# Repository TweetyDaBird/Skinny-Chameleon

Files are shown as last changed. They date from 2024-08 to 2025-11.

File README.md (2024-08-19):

# The Skinny Chameleon 

Chameleon

## Features
**The Skinny Chameleon is a grid type orthogonal keyboard with two optional layouts in one single PCB. It's a direct offshoot of the original Chameleon, only made to fit the Preonic's and Planck's non-standard key spacing.** Being able to break off the bottom row allows both a 5x12 layout acting as a replacement PCB for OLKB's Preonic and a 4x12 layout for the equally popular little brother Planck on the same PCB. 

Using the non-standard 19.00 mm grid spacing this PCB fit's all original cases for Preonic & Planck, and should fit all the various 'aftermarket' keyboard cases intended for these PCB's as well.

Being fully hot-swap and with PCB mounted stabilizers, Chameleon adds support for up to four encoders and a bottom row allowing either a single stabilized 2u key or two 2u keys in the middle, allowing for a layout that suits most users. If used as a 5 row keyboard, the bottom encoders can alternatively be placed at the edges on the second row, but **not more than one per corner.** 

The Chameleon features 8 bottomfacing RGB LEDs for underglow effects or to be used for layer indication or similar. 

**Please Note! This PCB fits original Planck/Preonic cases! NOT BM40/JJ40/JJ50!**

### Main Features:
* QMK and VIAL compatible, fully programmable keyboard**
* RP2040 MCU, Dual-core Arm Cortex M0+ processor, flexible clock running up to 133 MHz
* 264KB of SRAM, and 4MB of on-board Flash memory
* USB-C connector, (USB 1.1 device and host support)
* Low-power sleep and dormant modes
* Drag-and-drop programming using mass storage over USB
* Kaihl hot-swap sockets for Cherry MX compatible switches (3 & 5-pin)
* Cherry Style PCB mounted stabilizers
* Two main layouts:
	* 5x12 with 58 to 60 keys
	* 4x12 with 46 to 48 keys (Break off bottom row) 
* Configurable bottom row:
	* Full 1u grid
	* 1x centered, stabilized 2u key
	* 2x centered,  stabilized 2u keys

### Optional add-ons:
* Support for up to 4 rotary encoders **(one encoder per corner)**
* Optional RGB underglow (8x SK6812 mini-e)

**These options requires additional components not included in this listing and sold separately.**

## Assembly
**Little or no tools at all needed!** The PCB can be delivered fully soldered and ready to use, either as a full matrix, or with your selection of rotary encoders. If ordered fully soldered, the bottom row for the size specified (4x12/5x12) is soldered, and accepts both a full 1u grid and 2u keys without any changes.

**Or as a "DIY Kit" with some soldering needed**. As a DIY kit the hotswap sockets for the 6 encoder positions (corners) and the 2u keys are left unsoldered, and you can add them as your layout requires to corners not using an encoder, and to the bottom row you choose to use. (A total if 9 sockets included for soldering).

The optional RGB LED's needs to be soldered in place if used. (8 pcs, SK681x mini-E)

_The RGB LED's and encoders are all pre-soldered together with the required hotswap sockets at no extra cost, if the soldering option is selected and all parts needed are purchased in the same order._

# Case & Plate
**The design is made to fit any Planck or Preonic case and plate, and act as a drop-in replacement PCB.** It does *not* fit any case not advertised as specific fitment for these. 

**Any mounting hardware should accompany the case, and is not supplied with the PCB.** This means you will have to save and reuse the hardware with your originial case. 

**The solder on studs can be removed from your original PCB and re-used.**  Or, you can choose to buy replacement studs as an add-on, and not have to bother with the removal. Please note that the replacement studs are slightly loose in the holes to allow the use of both types (the original ones are a speciality item made for OLKB, I'm using the nearest off the shelf replacement), and they _absolutely need_ to be soldered on to the PCB to be useful. I highly suggest attaching them to the case, placing the PCB and solder as they are aligned.

***Change for version 1.10*** New PCB's will _NOT_ be able to fit the unusually sized original OLKB studs. Having to make a choice between the weird size making off the shelf studs be hard to center and re-using the original studs (which takes some skill), I'm choosing the off the shelf ones I can supply at a decent price. 
# Making Chameleon yourself
**Chameleon is open source / open hardware, and can be manufactured by anyone. The release contains all the neccesary files like parts lists, positions files etc for a full PCB/SMT production.** 

The formatting and files are geared towards [JLCPCB](http://jlcpcb.com), but never tested as such, as I only manufacture the PCB then do the assembly myself (at least until this reaches a volume justifying full SMT production).

The components are small enough that you would have to be highly skilled to attempt to assemble this either as hand soldered, or small scale/DIY SMT. I would highly recommend ordering the PCB as fully assembled unless you know you have the neccesary skill-set.

## Buy a kit!
I sell complete kits, making it easy to build your keyboard, and it also supports prototypes for new wacky ones. 



## Discord for build help and discussions!

<a href="https://discord.gg/G6QzcJQUnm">Discuss on Discord</a>

# License

[][cc-by-sa] - This work is licensed under a
[Creative Commons Attribution-ShareAlike 4.0 International License][cc-by-sa].

[cc-by-sa]: http://creativecommons.org/licenses/by-sa/4.0/
[cc-by-sa-shield]: https://img.shields.io/badge/License-CC%20BY--SA%204.0-lightgrey.svg

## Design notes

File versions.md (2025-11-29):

v1.20 - pushed out usb connector, refactored encoder footprints, refactored switch footprints with reinforced pads(larger via).

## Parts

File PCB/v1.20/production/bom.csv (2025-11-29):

Designator | Footprint | Quantity | Value | LCSC Part #
C1, C11, C12, C8 | 0402 | 4 | 1uF | C52923
C10, C13, C16, C17, C18, C19, C2, C20, C21, C22, C23, C3, C4, C5, C6, C7, C9 | 0402 | 17 | 100nF | C1525
C14, C15 | 0402 | 2 | 30pF | C1570
D1, D10, D11, D12, D13, D14, D15, D16, D17, D18, D19, D2, D20, D21, D22, D23, D24, D25, D26, D27, D28, D29, D3, D30, D31, D32, D33, D34, D35, D36, D37, D38, D39, D4, D40, D41, D42, D43, D44, D45, D46, D47, D48, D49, D5, D50, D51, D52, D53, D54, D55, D56, D57, D58, D59, D6, D60, D7, D8, D9 | D_SOD-323 | 60 | 1N4148W | C2128
F1 | 0603 | 1 | 0603L050/6AR | C163116
FB1, FB2 | 0603 | 2 | BLM18SG700TZ1D | C1002
R1, R2 | 0402 | 2 | 5.1K | C25905
R10, R4 | 0402 | 2 | 1K | C11702
R3, R7 | 0402 | 2 | 10K | C25744
R5, R6 | 0402 | 2 | 27R | C321419
SW10, SW11, SW13, SW14, SW15, SW16, SW17, SW18, SW19, SW2, SW20, SW21, SW22, SW23, SW24, SW25, SW26, SW27, SW28, SW29, SW3, SW30, SW31, SW32, SW33, SW34, SW35, SW36, SW38, SW39, SW4, SW40, SW41, SW42, SW43, SW44, SW45, SW46, SW47, SW5, SW50, SW51, SW52, SW53, SW54, SW55, SW56, SW57, SW58, SW59, SW6, SW61, SW62, SW63, SW64, SW65, SW66, SW7, SW8, SW9 | SW_MX_HotSwap_reinforced | 60 | PG151101S11 | C2803348
SW67, SW68 | YTSA010 | 2 | YTSA010 | C967783
U1 | SOT-23-5 | 1 | SPX3819M5-L-3-3/TR | C9055
U2 | USON-8_4x3mm_P0.8mm | 1 | W25Q32JVUUIQ | C2999380
U3 | QFN-56-1EP_7x7mm_P0.4mm_EP3.2x3.2mm | 1 | RP2040 | C2040
U4 | SOT-23-5 | 1 | SN74LV1T34DBV | C100024
U5 | SOT-23-6 | 1 | SRV05-4 | C20615829
USB1 | HRO_TYPE-C-31-M-12 | 1 | USB_C_Receptacle_USB2.0 | C165948
Y1 | Crystal_SMD_2520-4Pin_2.5x2.0mm | 1 | TXM12M0004252LBCEO00T | C284156

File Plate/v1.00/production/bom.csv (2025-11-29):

Designator | Footprint | Quantity | Value | LCSC Part #
SW1, SW10, SW11, SW12, SW13, SW14, SW15, SW16, SW17, SW18, SW19, SW2, SW20, SW21, SW22, SW23, SW24, SW25, SW26, SW27, SW28, SW29, SW3, SW30, SW31, SW32, SW33, SW34, SW35, SW36, SW37, SW38, SW39, SW4, SW40, SW41, SW42, SW44, SW45, SW46, SW47, SW48, SW5, SW50, SW51, SW52, SW53, SW54, SW57, SW58, SW59, SW6, SW63, SW7, SW8, SW9 | SW_MX_Plate_Placeholder_nodrill_NOBORDER_13,9 | 56 | PG151101S11 | C2803348

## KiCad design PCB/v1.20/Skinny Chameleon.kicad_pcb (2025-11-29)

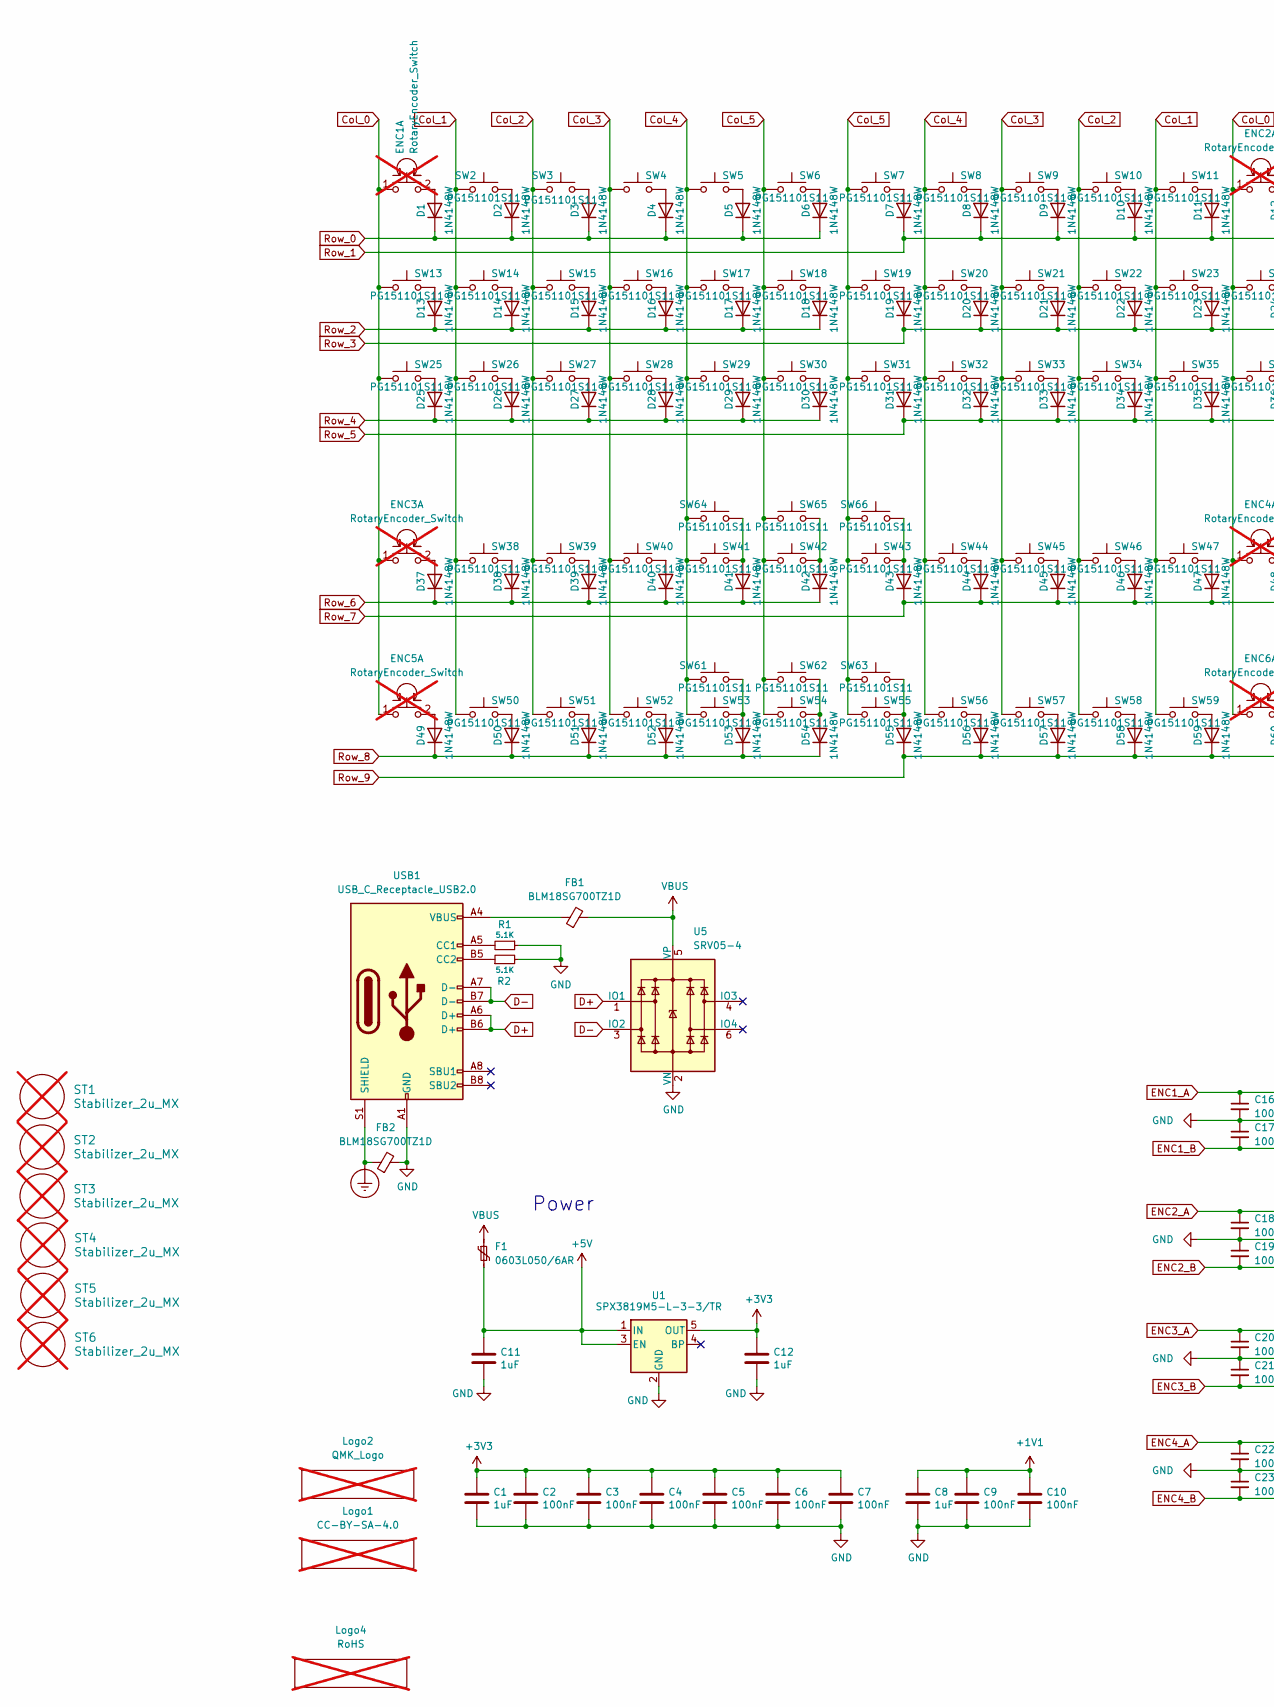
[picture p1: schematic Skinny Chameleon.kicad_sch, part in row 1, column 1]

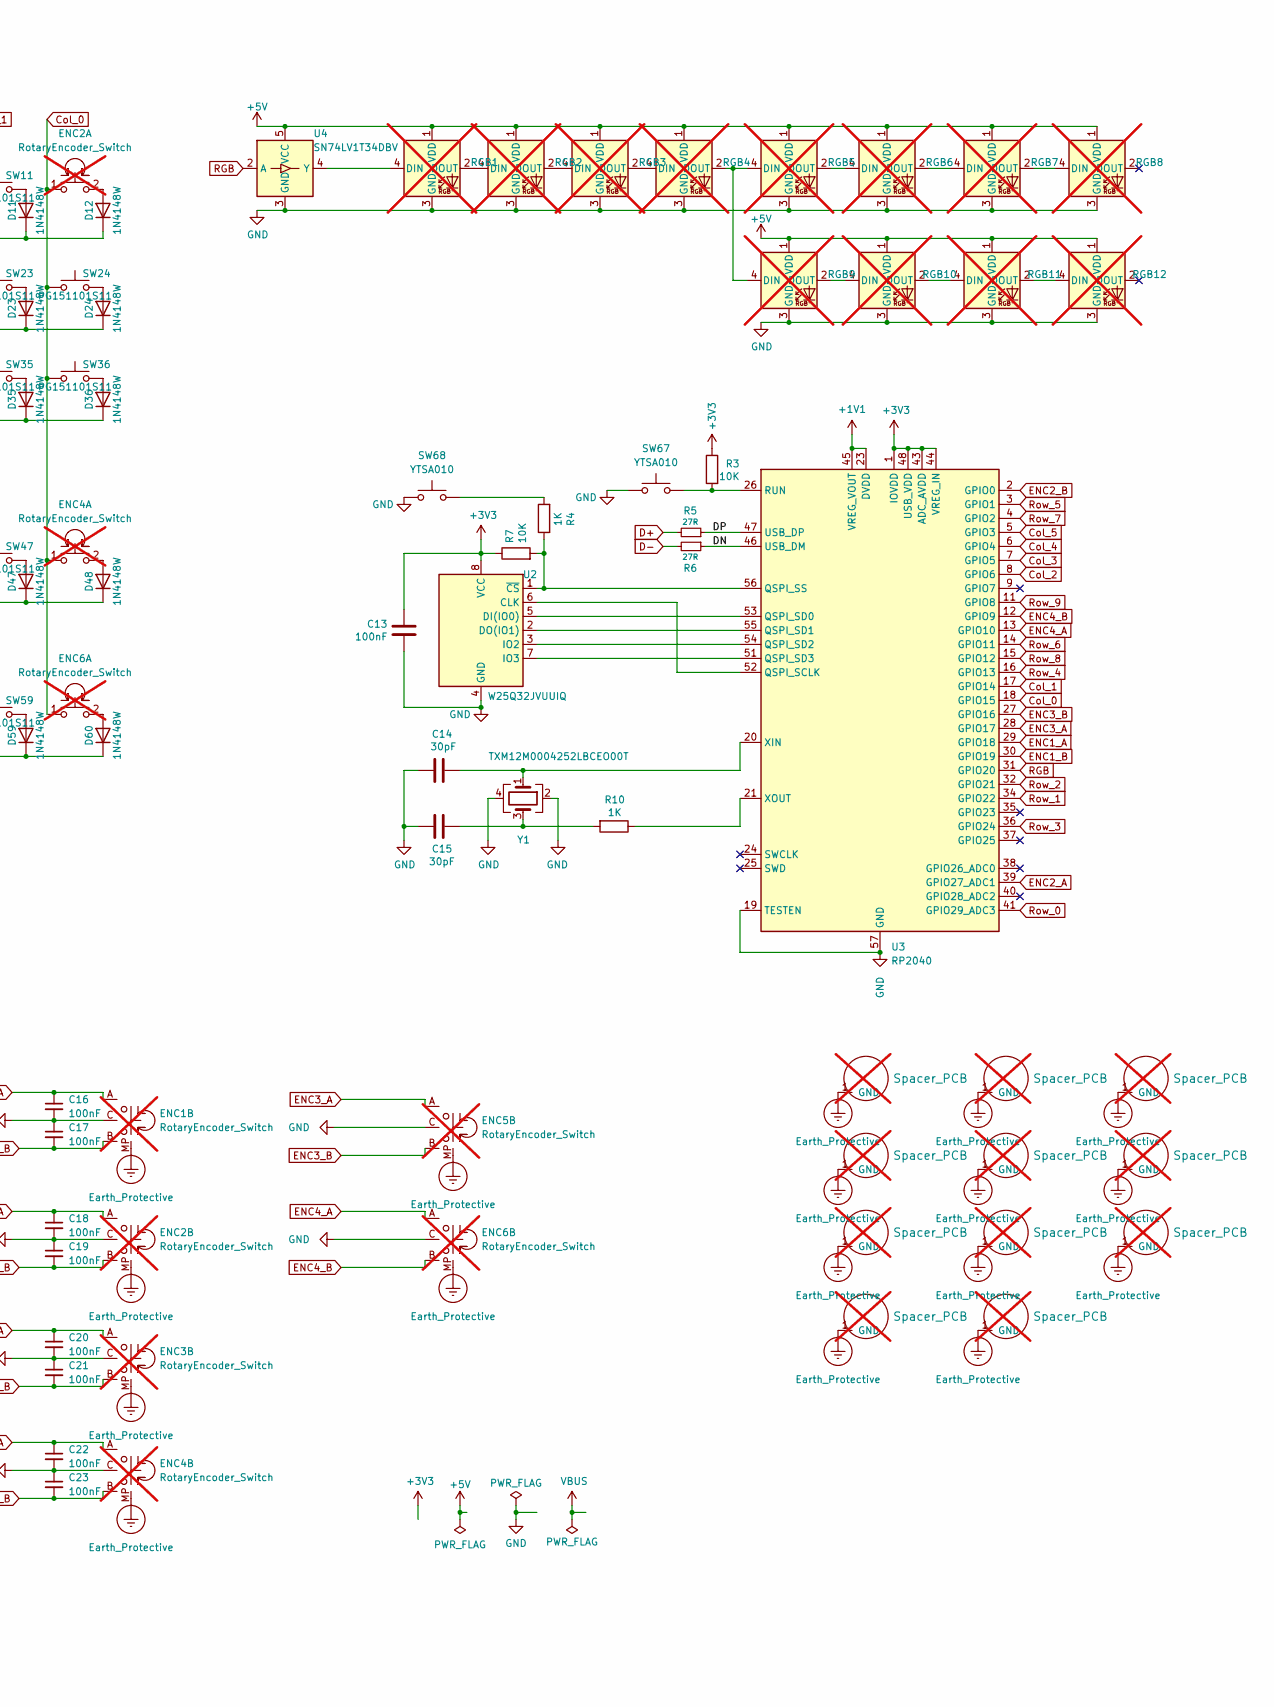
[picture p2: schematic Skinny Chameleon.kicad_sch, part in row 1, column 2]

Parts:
C1, C8, C11, C12: 1uF; C_0402_1005Metric; LCSC Part # C52923
C2, C3, C4, C5, C6, C7, C9, C10, C13, C16, C17, C18, C19, C20, C21, C22, C23: 100nF; C_0402_1005Metric; LCSC Part # C1525
C14, C15: 30pF; C_0402_1005Metric; LCSC Part # C1570
D1, D2, D3, D4, D5, D6, D7, D8, D9, D10, D11, D12, D13, D14, D15, D16, D17, D18, D19, D20, D21, D22, D23, D24, D25, D26, D27, D28, D29, D30, D31, D32, D33, D34, D35, D36, D37, D38, D39, D40, D41, D42, D43, D44, D45, D46, D47, D48, D49, D50, D51, D52, D53, D54, D55, D56, D57, D58, D59, D60: 1N4148W; D_SOD-323; LCSC Part # C2128
ENC1, ENC2: RotaryEncoder_Switch; SW_MX_HotSwap_Encoder_reinforced; not fitted
ENC3, ENC4, ENC5, ENC6: RotaryEncoder_Switch; SW_MX_HotSwap_Encoder_inverted_reinforced; not fitted
F1: 0603L050/6AR; R_0603_1608Metric; LCSC Part # C163116
FB1, FB2: BLM18SG700TZ1D; C_0603_1608Metric_Pad1.08x0.95mm_HandSolder; LCSC Part # C1002
H1, H2, H4, H5, H6, H7, H9, H11, H12, H13, H14: Spacer_PCB; Planck Spacer; not fitted
Logo1: CC-BY-SA-4.0; CC_BY_SA_40_line; not fitted
Logo2: QMK_Logo; qmk logo; not fitted
Logo4: RoHS; RoHs; not fitted
R1, R2: 5.1K; R_0402_1005Metric; LCSC Part # C25905
R3, R7: 10K; R_0402_1005Metric; LCSC Part # C25744
R4, R10: 1K; R_0402_1005Metric; LCSC Part # C11702
R5, R6: 27R; R_0402_1005Metric; LCSC Part # C321419
RGB1, RGB2, RGB3, RGB4, RGB5, RGB6, RGB7, RGB8, RGB9, RGB10, RGB11, RGB12: SK6812MINI-E; RGB_SK6812MINI-E; not fitted
ST1, ST2, ST3, ST4, ST5, ST6: Stabilizer_2u_MX; Stabilizer_Cherry_MX_2.00u; not fitted
SW2, SW3, SW4, SW5, SW6, SW7, SW8, SW9, SW10, SW11, SW13, SW14, SW15, SW16, SW17, SW18, SW19, SW20, SW21, SW22, SW23, SW24, SW25, SW26, SW27, SW28, SW29, SW30, SW31, SW32, SW33, SW34, SW35, SW36, SW38, SW39, SW40, SW41, SW42, SW43, SW44, SW45, SW46, SW47, SW50, SW51, SW52, SW53, SW54, SW55, SW56, SW57, SW58, SW59, SW61, SW62, SW63, SW64, SW65, SW66: PG151101S11; SW_MX_HotSwap_reinforced; LCSC Part # C2803348
SW67, SW68: YTSA010; LCSC Part # C967783
U1: SPX3819M5-L-3-3/TR; SOT-23-5; LCSC Part # C9055
U2: W25Q32JVUUIQ; USON-8_4x3mm_P0.8mm; LCSC Part # C2999380
U3: RP2040; QFN-56-1EP_7x7mm_P0.4mm_EP3.2x3.2mm; LCSC Part # C2040
U4: SN74LV1T34DBV; SOT-23-5; LCSC Part # C100024
U5: SRV05-4; SOT-23-6; LCSC Part # C20615829
USB1: USB_C_Receptacle_USB2.0; HRO_TYPE-C-31-M-12; LCSC Part # C165948
Y1: TXM12M0004252LBCEO00T; Crystal_SMD_2520-4Pin_2.5x2.0mm; LCSC Part # C284156

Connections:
+1V1: C8.1, C9.1, C10.1, U3.23 (DVDD), U3.45 (VREG_VOUT), U3.50 (DVDD)
+3V3: C1.1, C2.1, C3.1, C4.1, C5.1, C6.1, C7.1, C12.1, C13.1, R3.1, R7.1, U1.5 (OUT), U2.8 (VCC), U3.1 (IOVDD), U3.10 (IOVDD), U3.22 (IOVDD), U3.33 (IOVDD), U3.42 (IOVDD), U3.43 (ADC_AVDD), U3.44 (VREG_IN), U3.48 (USB_VDD), U3.49 (IOVDD)
+5V: C11.1, F1.2, RGB1.1 (VDD), RGB2.1 (VDD), RGB3.1 (VDD), RGB4.1 (VDD), RGB5.1 (VDD), RGB6.1 (VDD), RGB7.1 (VDD), RGB8.1 (VDD), RGB9.1 (VDD), RGB10.1 (VDD), RGB11.1 (VDD), RGB12.1 (VDD), U1.1 (IN), U1.3 (EN), U4.5 (VCC)
/DN: R6.1, U3.46 (USB_DM)
/DP: R5.1, U3.47 (USB_DP)
Col_0: ENC1.1, ENC1.S1, ENC2.1, ENC2.S1, ENC3.1, ENC3.S1, ENC4.1, ENC4.S1, ENC5.1, ENC5.S1, ENC6.1, ENC6.S1, SW13.1, SW24.1, SW25.1, SW36.1, U3.18 (GPIO15)
Col_1: SW2.2, SW11.1, SW14.1, SW23.1, SW26.1, SW35.1, SW38.1, SW47.1, SW50.1, SW59.1, U3.17 (GPIO14)
Col_2: SW3.2, SW10.1, SW15.1, SW22.1, SW27.1, SW34.1, SW39.1, SW46.1, SW51.1, SW58.1, U3.8 (GPIO6)
Col_3: SW4.1, SW9.1, SW16.1, SW21.1, SW28.1, SW33.1, SW40.1, SW45.1, SW52.1, SW57.1, U3.7 (GPIO5)
Col_4: SW5.1, SW8.1, SW17.1, SW20.1, SW29.1, SW32.1, SW41.1, SW44.1, SW53.1, SW56.1, SW61.2, SW64.2, U3.6 (GPIO4)
Col_5: SW6.1, SW7.1, SW18.1, SW19.1, SW30.1, SW31.1, SW42.1, SW43.1, SW54.1, SW55.1, SW62.1, SW63.2, SW65.1, SW66.2, U3.5 (GPIO3)
D+: R5.2, U5.1 (IO1), USB1.A6 (D+), USB1.B6 (D+)
D-: R6.2, U5.3 (IO2), USB1.A7 (D-), USB1.B7 (D-)
ENC1_A: C16.1, ENC1.A, U3.29 (GPIO18)
ENC1_B: C17.2, ENC1.B, U3.30 (GPIO19)
ENC2_A: C18.1, ENC2.A, U3.39 (GPIO27_ADC1)
ENC2_B: C19.2, ENC2.B, U3.2 (GPIO0)
ENC3_A: C20.1, ENC3.A, ENC5.A, U3.28 (GPIO17)
ENC3_B: C21.2, ENC3.B, ENC5.B, U3.27 (GPIO16)
ENC4_A: C22.1, ENC4.A, ENC6.A, U3.13 (GPIO10)
ENC4_B: C23.2, ENC4.B, ENC6.B, U3.12 (GPIO9)
unnamed: C15.1, R10.2, Y1.3
unnamed: D1.2 (A), ENC1.2, ENC1.S2
unnamed: D2.2 (A), SW2.1
unnamed: D3.2 (A), SW3.1
unnamed: D4.2 (A), SW4.2
unnamed: D5.2 (A), SW5.2
unnamed: D6.2 (A), SW6.2
unnamed: D7.2 (A), SW7.2
unnamed: D8.2 (A), SW8.2
unnamed: D9.2 (A), SW9.2
unnamed: D10.2 (A), SW10.2
unnamed: D11.2 (A), SW11.2
unnamed: D12.2 (A), ENC2.2, ENC2.S2
unnamed: D13.2 (A), SW13.2
unnamed: D14.2 (A), SW14.2
unnamed: D15.2 (A), SW15.2
unnamed: D16.2 (A), SW16.2
unnamed: D17.2 (A), SW17.2
unnamed: D18.2 (A), SW18.2
unnamed: D19.2 (A), SW19.2
unnamed: D20.2 (A), SW20.2
unnamed: D21.2 (A), SW21.2
unnamed: D22.2 (A), SW22.2
unnamed: D23.2 (A), SW23.2
unnamed: D24.2 (A), SW24.2
unnamed: D25.2 (A), SW25.2
unnamed: D26.2 (A), SW26.2
unnamed: D27.2 (A), SW27.2
unnamed: D28.2 (A), SW28.2
unnamed: D29.2 (A), SW29.2
unnamed: D30.2 (A), SW30.2
unnamed: D31.2 (A), SW31.2
unnamed: D32.2 (A), SW32.2
unnamed: D33.2 (A), SW33.2
unnamed: D34.2 (A), SW34.2
unnamed: D35.2 (A), SW35.2
unnamed: D36.2 (A), SW36.2
unnamed: D37.2 (A), ENC3.2, ENC3.S2
unnamed: D38.2 (A), SW38.2
unnamed: D39.2 (A), SW39.2
unnamed: D40.2 (A), SW40.2
unnamed: D41.2 (A), SW41.2, SW64.1
unnamed: D42.2 (A), SW42.2, SW65.2
unnamed: D43.2 (A), SW43.2, SW66.1
unnamed: D44.2 (A), SW44.2
unnamed: D45.2 (A), SW45.2
unnamed: D46.2 (A), SW46.2
unnamed: D47.2 (A), SW47.2
unnamed: D48.2 (A), ENC4.2, ENC4.S2
unnamed: D49.2 (A), ENC5.2, ENC5.S2
unnamed: D50.2 (A), SW50.2
unnamed: D51.2 (A), SW51.2
unnamed: D52.2 (A), SW52.2
unnamed: D53.2 (A), SW53.2, SW61.1
unnamed: D54.2 (A), SW54.2, SW62.2
unnamed: D55.2 (A), SW55.2, SW63.1
unnamed: D56.2 (A), SW56.2
unnamed: D57.2 (A), SW57.2
unnamed: D58.2 (A), SW58.2
unnamed: D59.2 (A), SW59.2
unnamed: D60.2 (A), ENC6.2, ENC6.S2
unnamed: FB1.1, USB1.A4 (VBUS), USB1.A9 (VBUS), USB1.B4 (VBUS), USB1.B9 (VBUS)
unnamed: R4.2, SW68.2
unnamed: RGB1.4 (DIN), U4.4 (Y)
unnamed: RGB1.2 (DOUT), RGB2.4 (DIN)
unnamed: RGB2.2 (DOUT), RGB3.4 (DIN)
unnamed: RGB3.2 (DOUT), RGB4.4 (DIN)
unnamed: RGB4.2 (DOUT), RGB5.4 (DIN), RGB9.4 (DIN)
unnamed: RGB5.2 (DOUT), RGB6.4 (DIN)
unnamed: RGB6.2 (DOUT), RGB7.4 (DIN)
unnamed: RGB7.2 (DOUT), RGB8.4 (DIN)
unnamed: RGB9.2 (DOUT), RGB10.4 (DIN)
unnamed: RGB10.2 (DOUT), RGB11.4 (DIN)
unnamed: RGB11.2 (DOUT), RGB12.4 (DIN)
unnamed: U2.6 (CLK), U3.52 (QSPI_SCLK)
unnamed: U2.5 (DI(IO0)), U3.53 (QSPI_SD0)
unnamed: U2.2 (DO(IO1)), U3.55 (QSPI_SD1)
unnamed: U2.3 (IO2), U3.54 (QSPI_SD2)
unnamed: U2.7 (IO3), U3.51 (QSPI_SD3)
unnamed: R4.1, R7.2, U2.1 (~CS), U3.56 (QSPI_SS)
unnamed: R3.2, SW67.2, U3.26 (RUN)
unnamed: C14.1, U3.20 (XIN), Y1.1
unnamed: R10.1, U3.21 (XOUT)
unnamed: R1.2, USB1.A5 (CC1)
unnamed: R2.1, USB1.B5 (CC2)
RGB: U3.31 (GPIO20), U4.2 (A)
Row_0: D1.1 (K), D2.1 (K), D3.1 (K), D4.1 (K), D5.1 (K), D6.1 (K), U3.41 (GPIO29_ADC3)
Row_1: D7.1 (K), D8.1 (K), D9.1 (K), D10.1 (K), D11.1 (K), D12.1 (K), U3.34 (GPIO22)
Row_2: D13.1 (K), D14.1 (K), D15.1 (K), D16.1 (K), D17.1 (K), D18.1 (K), U3.32 (GPIO21)
Row_3: D19.1 (K), D20.1 (K), D21.1 (K), D22.1 (K), D23.1 (K), D24.1 (K), U3.36 (GPIO24)
Row_4: D25.1 (K), D26.1 (K), D27.1 (K), D28.1 (K), D29.1 (K), D30.1 (K), U3.16 (GPIO13)
Row_5: D31.1 (K), D32.1 (K), D33.1 (K), D34.1 (K), D35.1 (K), D36.1 (K), U3.3 (GPIO1)
Row_6: D37.1 (K), D38.1 (K), D39.1 (K), D40.1 (K), D41.1 (K), D42.1 (K), U3.14 (GPIO11)
Row_7: D43.1 (K), D44.1 (K), D45.1 (K), D46.1 (K), D47.1 (K), D48.1 (K), U3.4 (GPIO2)
Row_8: D49.1 (K), D50.1 (K), D51.1 (K), D52.1 (K), D53.1 (K), D54.1 (K), U3.15 (GPIO12)
Row_9: D55.1 (K), D56.1 (K), D57.1 (K), D58.1 (K), D59.1 (K), D60.1 (K), U3.11 (GPIO8)
VBUS: F1.1, FB1.2, U5.5 (VP)

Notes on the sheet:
Power

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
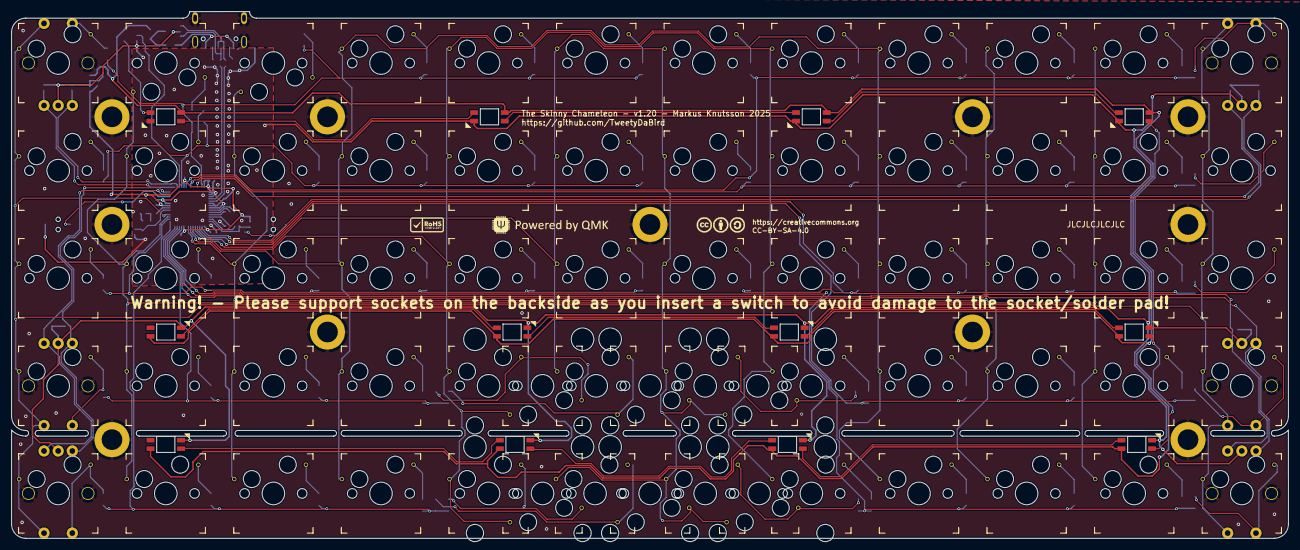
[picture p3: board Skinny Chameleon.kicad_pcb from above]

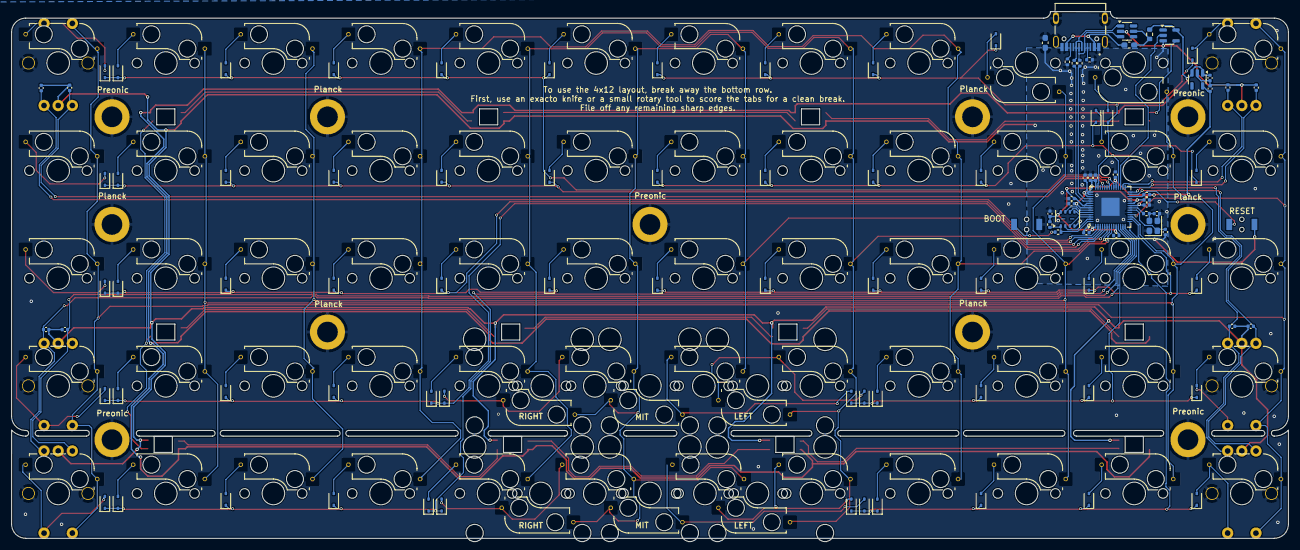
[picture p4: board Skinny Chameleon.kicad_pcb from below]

Board: 2 copper layers, 225.4 x 93.0 mm, 201 parts (115 on the bottom side), 120 nets.

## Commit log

2024-08-19 Skinny Chameleon v1.00
    Initial design
    [Skinny Chameleon.kicad_sch, bom.csv, designators.csv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]
2024-08-19 Skinny Chameleon v 1.10
    - Corrected mounting hole position for Planck layout
    - Smaller hole on solder ring for spacers
    - Re-centered USB port.
    [Skinny Chameleon.kicad_sch, bom.csv, positions.csv]
2025-03-25 Skinny Chameleon v1.11
    [Skinny Chameleon.kicad_sch, bom.csv, designators.csv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]
2025-08-01 V1.11
    Corrections to silkscreen.
    Marking the spacer mounting holes for Planck/Preonic
    Marking Sockets for layout.
    Added socket warning.
    Add RoHS marking.
2025-11-29 Added plate for Skinny Chameleon & BLE
    Moved folders around
    [Chameleon Plate.kicad_pcb, Chameleon Plate.kicad_sch, Skinny Chameleon.kicad_sch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]
2025-11-29 Added v 1.20
    - Moved USB out for better case fitment.
    - Added via's for pad reinforment.
    [Skinny Chameleon.kicad_pcb, Skinny Chameleon.kicad_sch, bom.csv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]
2026-11-10 PCB Version
2026-11-10 Update interactive BOM
2026-11-10 Update BOM HTML preview link in README.md
2026-11-10 Simplify README for interactive BOM
    Removed redundant notes about BOM quantities and calculations.

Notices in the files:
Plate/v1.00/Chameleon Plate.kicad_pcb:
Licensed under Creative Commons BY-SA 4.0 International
